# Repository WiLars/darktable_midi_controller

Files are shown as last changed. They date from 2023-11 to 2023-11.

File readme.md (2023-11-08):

# Midi controller for darktable

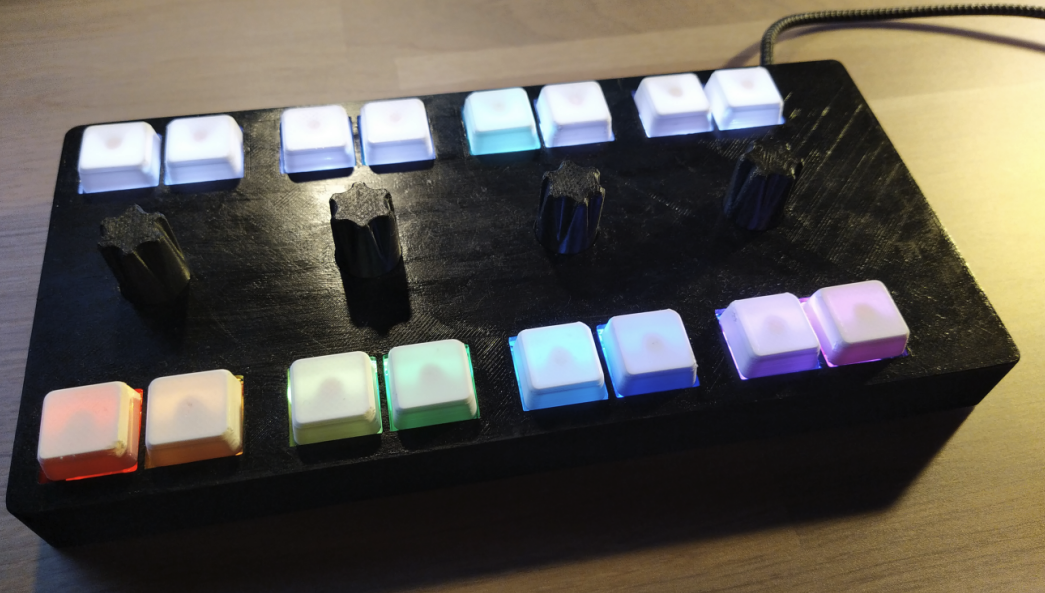
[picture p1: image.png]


- 3D printed housing
  -  stp and stl files available  
- individually illuminated buttons depending on state of the controller using WS2812 RGB LEDs
- arduino compatible pro micro µc
  - extended input channels with 74HC165 shifht registers
  - cherry type mechanical keys
    - 8 top row for mode selction
    - 8 in bottom row for functions
  - 4 alps rotary encoders with button functions
  - powered and connected via usb
- PCB files in KiCad available
- control of darktable via midi protcol
  - fully customizable inside of darktable

## materials
| Part | amount | comment|
| --- | --- | --- |
| PCB | 1 | Kicad files in this repo|
| frontcover | 1 | 3D print|
| backcover | 1 | 3D print|
| LED holder | 1 | 3D print|
| buffer | 7 | 3D print (TPU)|
| encoder knobs | 4 | 3D print|
| keycaps | 16 | 3D print|
| M3x10 screw | 7| |
| micro USB cable| 1 | |
| pro micro atmega32 | 1| arduino compatible cheap MCU|
| 74HC165 | 2|  shift registers|
| cherry type switches | 16 | accordig to taste|
| capacitor 100 nF | 2 | |
| capacitor 1 µF | 2 | or something similar |
| rotary encoder Alps EC12 | 4 | with click|
| pullup resistor | 16 | high resistance recommended > 10k Ohm |
| WS2812 RGB LED | 16 | I used a self adhesive LED strip with 60 LED/m, that way, two can be chained without soldering |
| double tape | some |  to stick the LED holder onto the PCB|
| wire | some | to connect LED strips |

## assembly
- solder al compenents to PCB
- LEDs: this is a little awkward, spacing of LEDs and switches didn't fit and I could't source any reasonably priced THT RGB LEDs
  - two LEDs from the strip are glued to the holder, position is indicated by notches
  - individual strips need to be connected with wire (3 contacts each)
  - LED holder can be glued onto the PCB with some double tape
  - then both strips (top and bottom can be connected to the PCB

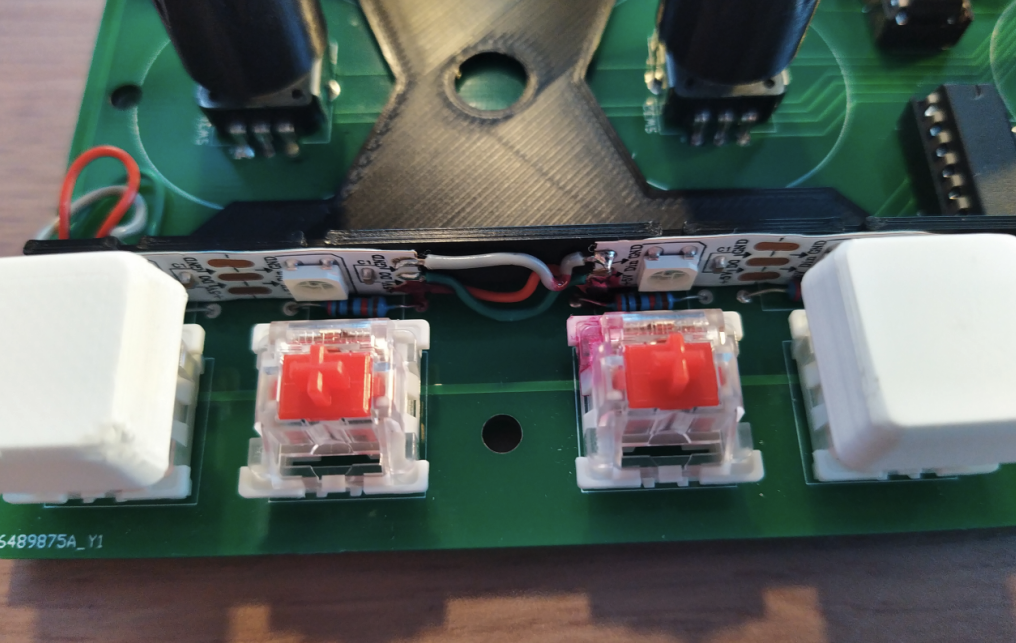
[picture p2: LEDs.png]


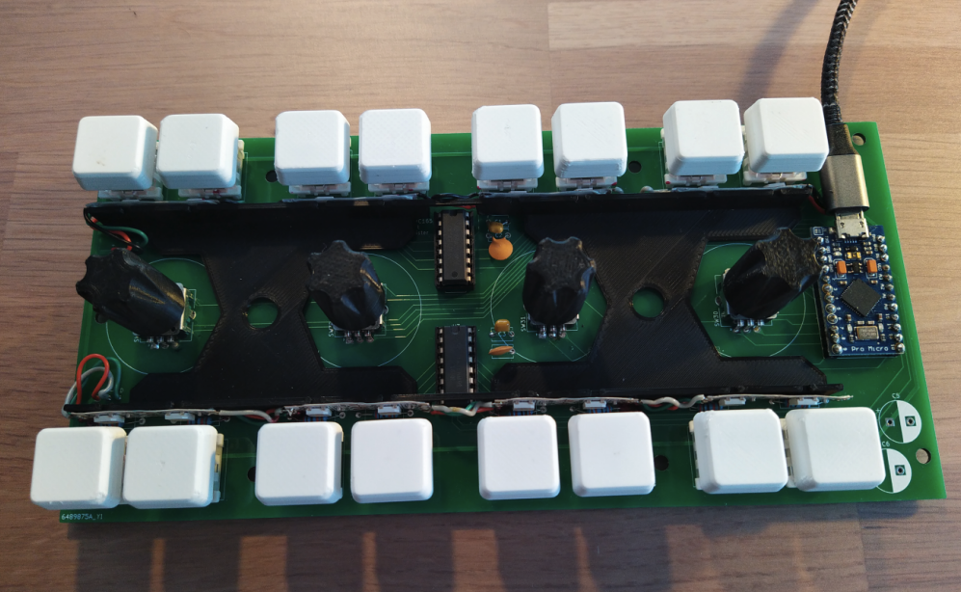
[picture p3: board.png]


- add USB cable
- add TPU buffers to the backcover
- add the case and screws
- knobs and keycaps
- flash arduino SW

## usage
*The controller must be connected during start of darktable, it can only be detected during start!*
after every start, darktable needs to notice that midi CCs are working in relative mode (default is absolute). This can be done by rotating one of the encoders left.

If darktable is running in absolute encoding, input can be reset with ctrl+alt*shift+I then again try to rotate an encoder left.

keymappsings can be imported into darktable: settings -> shortcuts -> import
 => use file *darktable_shortcut_mapping_export*

 With current arduino SW the top row of switches selects the modes, bottom row of buttons and rotary encoders can be assigned to darktable functions

 ## issues
 - darktable does not distinguish for very low "notes" for midi, therefore some buttons cannot be assigned
 - keymapping is not very complete

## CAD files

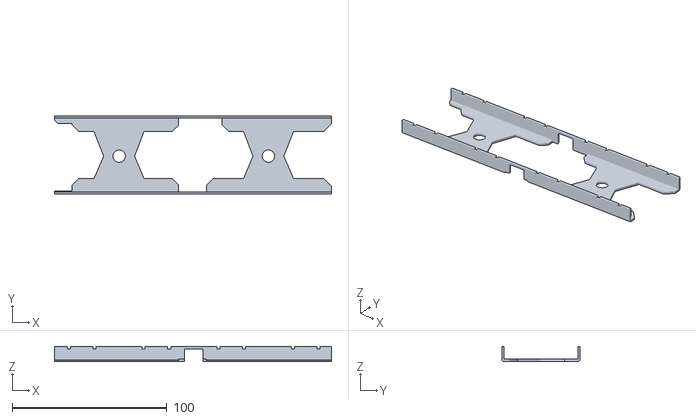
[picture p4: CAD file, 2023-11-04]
3d print parts/LED_holder.stl
179.1 x 50.7 x 9.50

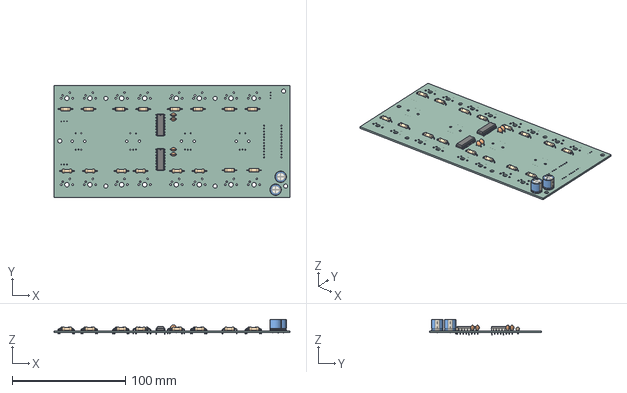
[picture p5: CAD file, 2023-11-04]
PCB_KiCAD/photo console.step
208.3 x 99.1 x 13.3 mm
photo console PCB

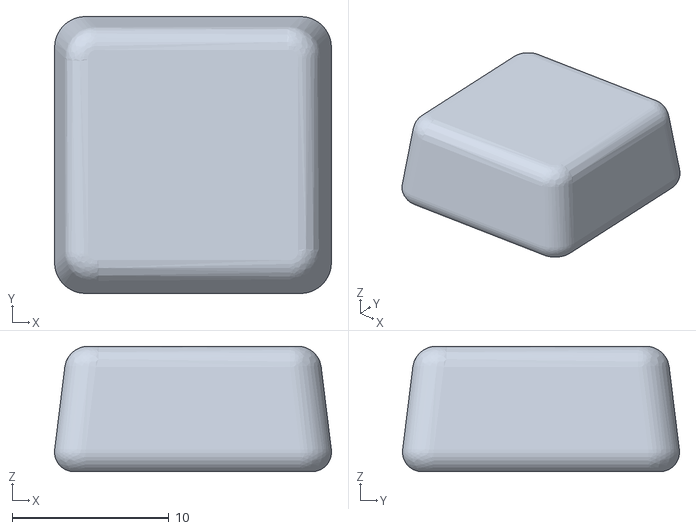
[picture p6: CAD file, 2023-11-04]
3d print parts/key_cap.stl
17.7 x 17.7 x 8.00

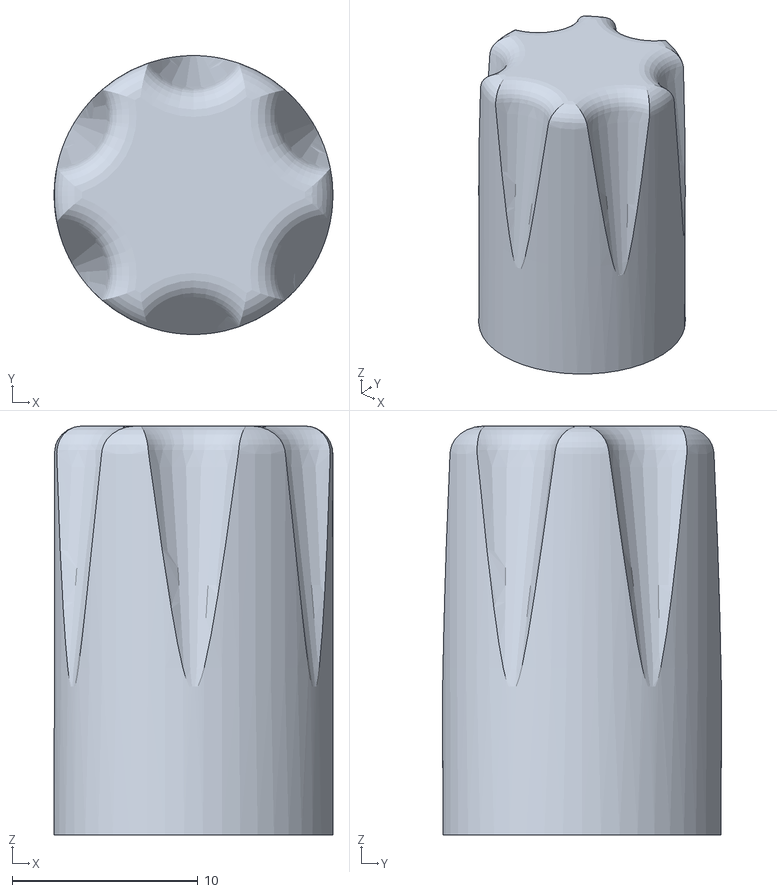
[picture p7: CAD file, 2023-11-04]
3d print parts/rotary_knob.stl
15.0 x 15.0 x 22.0

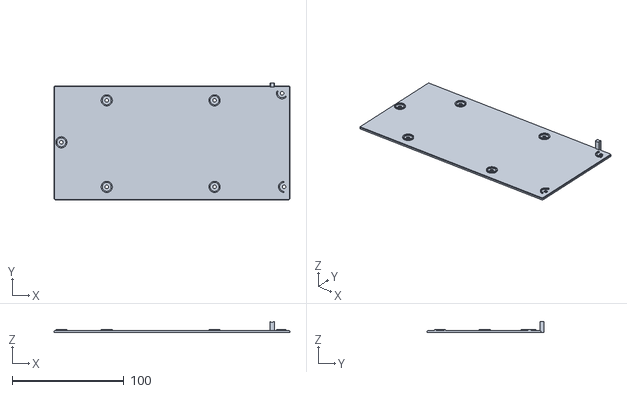
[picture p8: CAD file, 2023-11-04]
3d print parts/backcover.stl
211.3 x 104.6 x 10.2

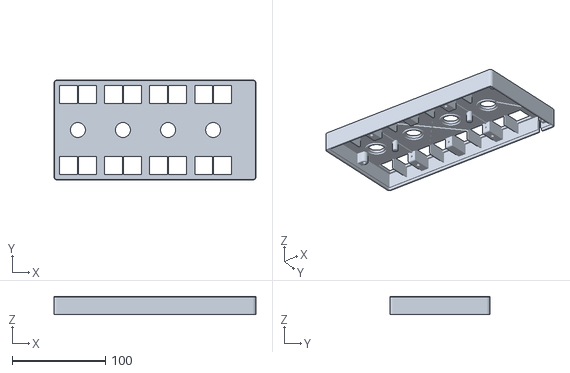
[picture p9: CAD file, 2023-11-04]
3d print parts/housing.stl
216.3 x 107.1 x 19.6

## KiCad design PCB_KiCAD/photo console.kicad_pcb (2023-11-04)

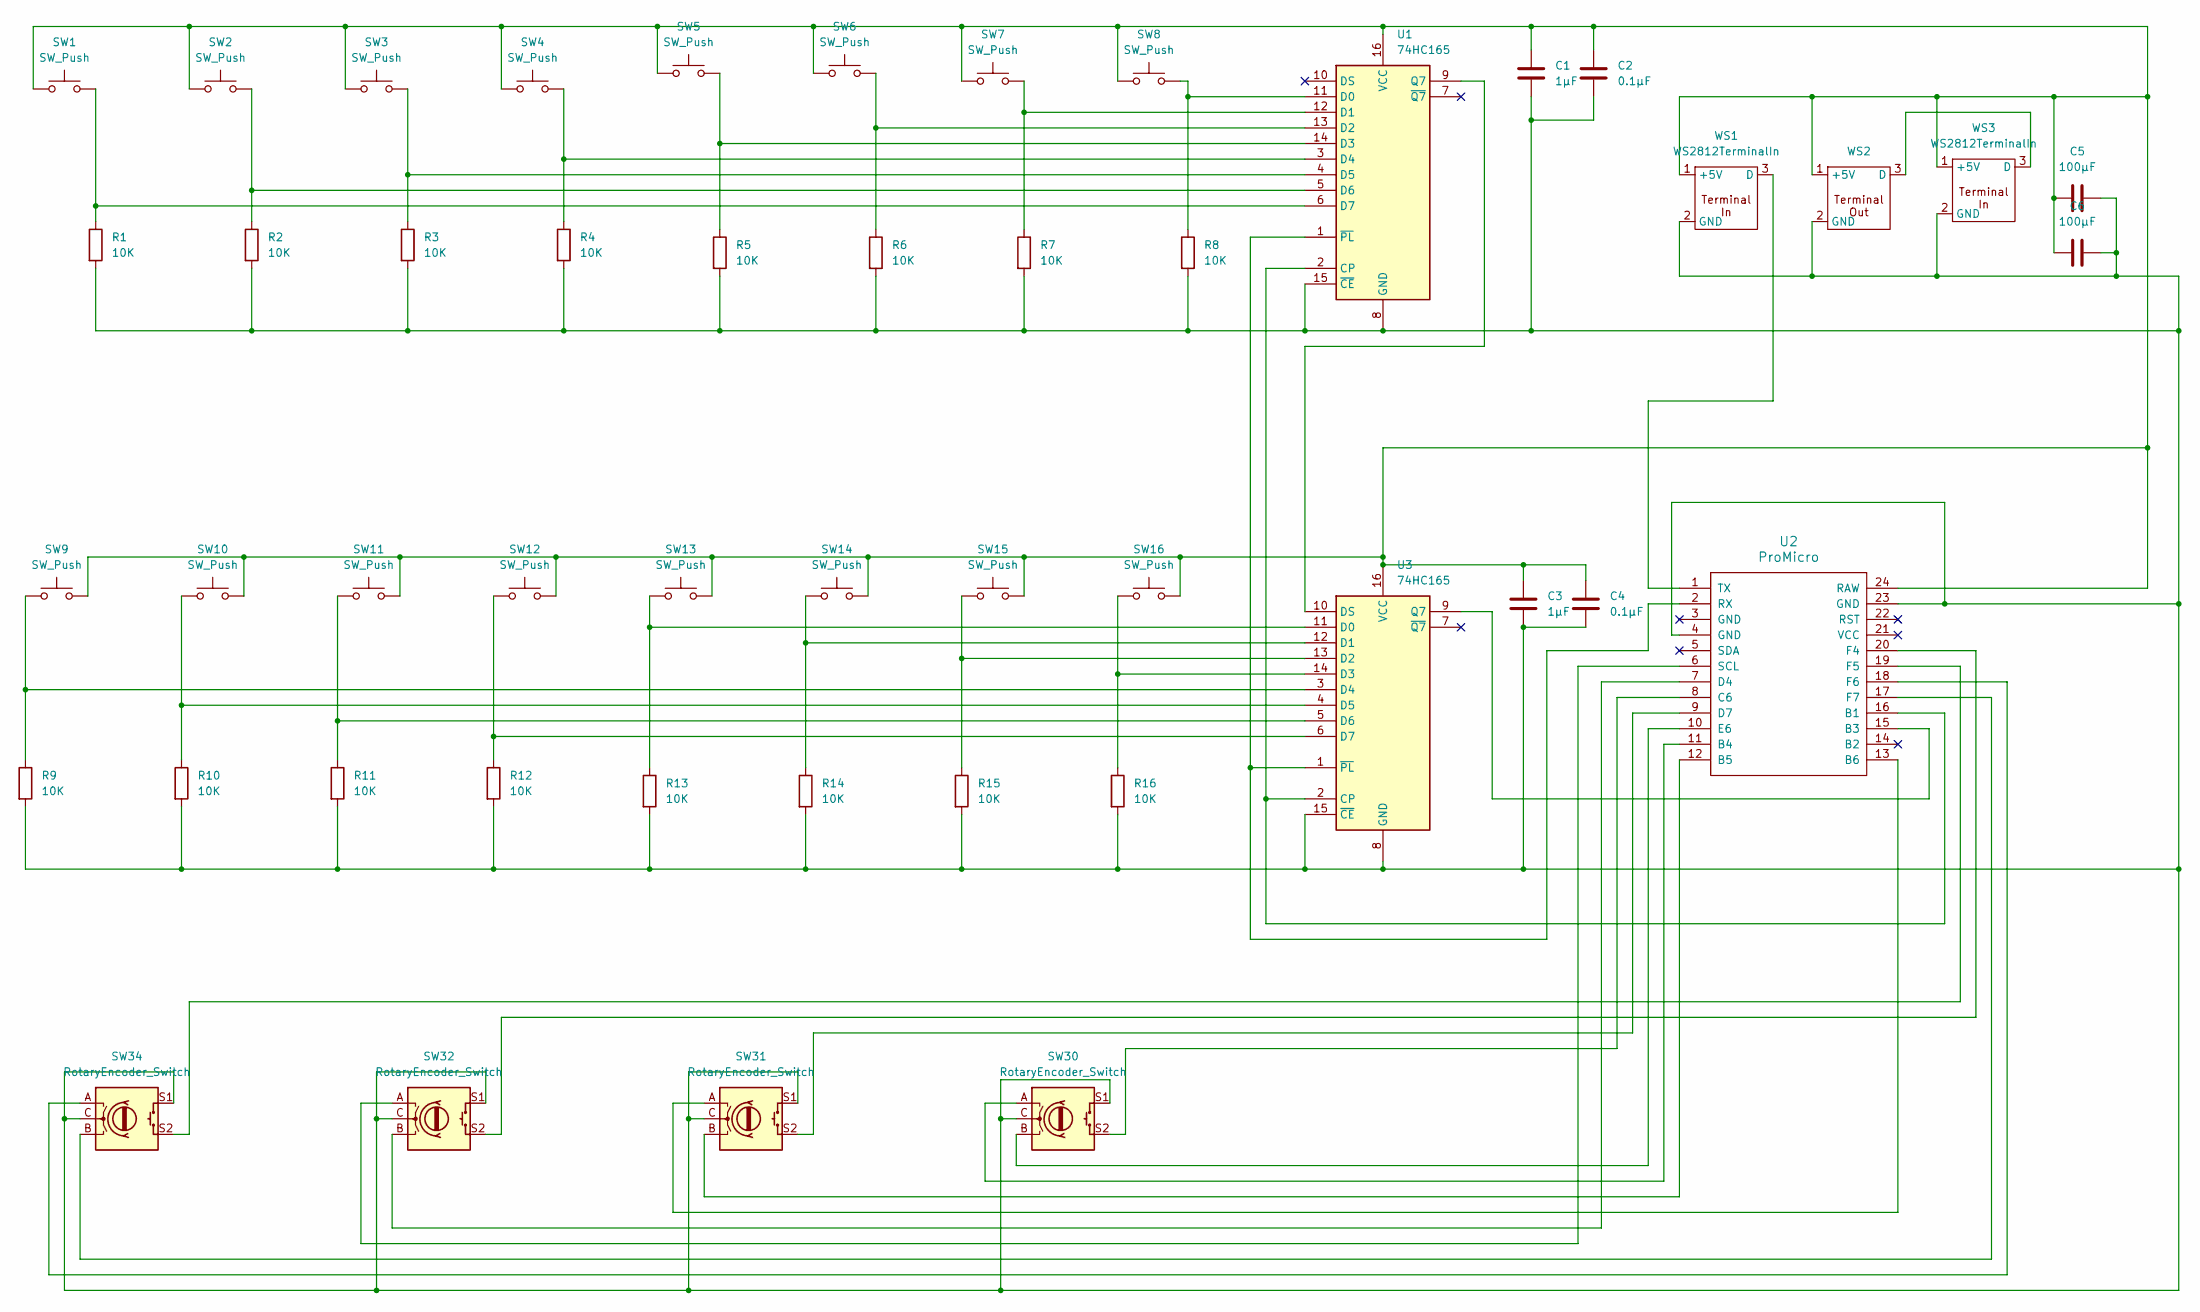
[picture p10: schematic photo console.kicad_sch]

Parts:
C1, C3: 1µF; C_Disc_D5.1mm_W3.2mm_P5.00mm
C2, C4: 0.1µF; C_Disc_D5.1mm_W3.2mm_P5.00mm
C5, C6: 100µF; CP_Radial_D10.0mm_P5.00mm
R1, R2, R3, R4, R5, R6, R7, R8, R9, R10, R11, R12, R13, R14, R15, R16: 10K; R_Axial_DIN0309_L9.0mm_D3.2mm_P12.70mm_Horizontal
SW1, SW2, SW3, SW4, SW5, SW6, SW7, SW8, SW9, SW10, SW11, SW12, SW13, SW14, SW15, SW16: SW_Push; SW_Cherry_MX_1.00u_PCB_center_hole
SW30, SW31, SW32, SW34: RotaryEncoder_Switch; RotaryEncoder_Alps_EC12E-Switch_Vertical_H20mm_CircularMoun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
U1, U3: 74HC165; DIP-16_W7.62mm
U2: ProMicro
WS1, WS3: WS2812TerminalIn; 3 Pin THT
WS2: 3 Pin THT

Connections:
unnamed: U1.2 (CP), U2.16 (B1), U3.2 (CP)
unnamed: R8.1, SW8.2, U1.11 (D0)
unnamed: R7.1, SW7.2, U1.12 (D1)
unnamed: R6.1, SW6.2, U1.13 (D2)
unnamed: R5.1, SW5.2, U1.14 (D3)
unnamed: R4.1, SW4.2, U1.3 (D4)
unnamed: R3.1, SW3.2, U1.4 (D5)
unnamed: R2.1, SW2.2, U1.5 (D6)
unnamed: R1.1, SW1.2, U1.6 (D7)
unnamed: C1.2, C2.2, C3.2, C4.2, C5.2, C6.2, R1.2, R2.2, R3.2, R4.2, R5.2, R6.2, R7.2, R8.2, R9.2, R10.2, R11.2, R12.2, R13.2, R14.2, R15.2, R16.2, SW30.C, SW30.S1, SW31.C, SW31.S1, SW32.C, SW32.S1, SW34.C, SW34.S1, U1.8 (GND), U1.15 (~CE), U2.4 (GND), U2.23 (GND), U3.8 (GND), U3.15 (~CE), WS1.2 (GND), WS2.2 (GND), WS3.2 (GND)
unnamed: U1.9 (Q7), U3.10 (DS)
unnamed: C1.1, C2.1, C3.1, C4.1, C5.1, C6.1, SW1.1, SW2.1, SW3.1, SW4.1, SW5.1, SW6.1, SW7.1, SW8.1, SW9.2, SW10.2, SW11.2, SW12.2, SW13.2, SW14.2, SW15.2, SW16.2, U1.16 (VCC), U2.24 (RAW), U3.16 (VCC), WS1.1 (+5V), WS2.1 (+5V), WS3.1 (+5V)
unnamed: U1.1 (~PL), U2.2 (RX), U3.1 (~PL)
unnamed: U2.15 (B3), U3.9 (Q7)
unnamed: SW30.A, U2.11 (B4)
unnamed: SW31.B, U2.12 (B5)
unnamed: SW31.A, U2.13 (B6)
unnamed: SW30.S2, U2.8 (C6)
unnamed: SW32.B, U2.7 (D4)
unnamed: SW31.S2, U2.9 (D7)
unnamed: SW30.B, U2.10 (E6)
unnamed: SW32.S2, U2.20 (F4)
unnamed: SW34.S2, U2.19 (F5)
unnamed: SW34.A, U2.18 (F6)
unnamed: SW34.B, U2.17 (F7)
unnamed: SW32.A, U2.6 (SCL)
unnamed: U2.1 (TX), WS1.3 (D)
unnamed: R13.1, SW13.1, U3.11 (D0)
unnamed: R14.1, SW14.1, U3.12 (D1)
unnamed: R15.1, SW15.1, U3.13 (D2)
unnamed: R16.1, SW16.1, U3.14 (D3)
unnamed: R9.1, SW9.1, U3.3 (D4)
unnamed: R10.1, SW10.1, U3.4 (D5)
unnamed: R11.1, SW11.1, U3.5 (D6)
unnamed: R12.1, SW12.1, U3.6 (D7)
unnamed: WS2.3 (D), WS3.3 (D)

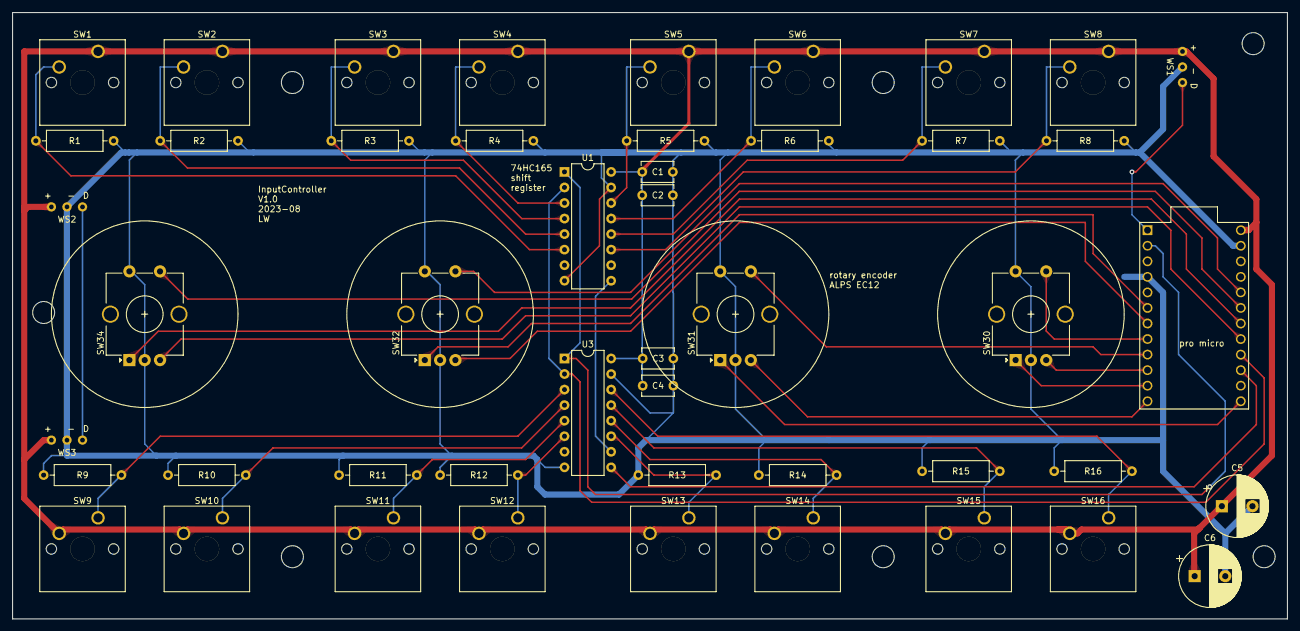
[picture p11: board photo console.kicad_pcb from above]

Board: 2 copper layers, 208.3 x 99.1 mm, 48 parts (0 on the bottom side), 36 nets.

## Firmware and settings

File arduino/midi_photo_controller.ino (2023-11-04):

#include <MIDIUSB.h>
#include <MIDIUSB_Defs.h>
//#include <pitchToNote.h>
//#include <frequencyToNote.h>
//#include <pitchToFrequency.h>


#include <Adafruit_NeoPixel.h>
#include <SPI.h>
#include <ClickEncoder.h>
#include <TimerOne.h>
//#include <Keyboard.h>



const byte LATCH = 0; // shift register pulse

//LED
const byte LEDPIN = 1;

byte LED_R[16] = {127,127,127,127,127,127,127,127,127,127,127,127,127,127,127,127};
byte LED_G[16] = {127,0,127,0,0,0,0,0,0,0,0,0,0,0,0,0};
byte LED_B[16] = {127,127,0,0,0,0,0,127,0,0,0,0,0,0,0,0};
Adafruit_NeoPixel strip = Adafruit_NeoPixel(16, LEDPIN, NEO_GRB + NEO_KHZ800);

byte mode = 0;
byte midi_val = 127;
//-----THIS BLOCK HANDLES ENCODER INPUT-----
//Encoder 1
ClickEncoder *encoder0;      // Dreh-Enkoder mit Klickbutton
ClickEncoder *encoder1;
ClickEncoder *encoder2;      // Dreh-Enkoder mit Klickbutton
ClickEncoder *encoder3;

bool enchold[4];
static int16_t enclastval[4] = {0,0,0,0};

void timerIsr() {
  encoder0->service();
  encoder1->service();
  encoder2->service();
  encoder3->service();
}

void ReadEncoder(int encindex){
  ClickEncoder *encoder;
  if (encindex==0){
    encoder=encoder0;}
  else if (encindex==1){
    encoder=encoder1;}
     else if (encindex==2){
    encoder=encoder2;}
      else if (encindex==3){
    encoder=encoder3;}


int encValue = encoder->getValue();
if (encValue != 0) {
    enclastval[encindex] += encValue;
    byte midi_send =0;
    byte control_channel = mode*4+encindex;
    if (encValue < 0){
      midi_send = 1;}
    else if (encValue > 0){
      midi_send = 127;}
    Serial.print (control_channel);
    Serial.println (midi_send);
 for (uint16_t i=0; i<abs(encValue);i++){ // darktable scheint im relativen encoding nur +1 (=1) und -1 (=127) zu verstehen, deshalb muss für encoder accel das commando einfach mehrfach geschickt werden
    controlChange(0, control_channel, midi_send);
  }
    MidiUSB.flush();
    //Serial.print (encindex);
    //Serial.print (enclastval[encindex] );
    //Serial.println (encValue);
    }

ClickEncoder::Button b = encoder->getButton();     // den Button-Status abfragen
if (b != ClickEncoder::Open) {
    switch (b) {                                     // und entsprechend darauf reagieren
      case ClickEncoder::Clicked:                    // Button wurde einmal angeklickt
        Serial.println (encindex*2+8+mode*16);

        noteOn(0, encindex*2+8+mode*16, 127);
        MidiUSB.flush();
        noteOff(0, encindex*2+8+mode*16, 127);
        MidiUSB.flush();
        break;
      case ClickEncoder::DoubleClicked:              // Doppelklick auf den Button
        Serial.println (encindex*2+8+1+mode*16);
        noteOn(0, encindex*2+8+1+mode*16, 127);
        MidiUSB.flush();
        noteOff(0, encindex*2+8+1+mode*16, 127);
        MidiUSB.flush();
        break;
//      case ClickEncoder::Held:                       // Button gedrueckt halten
//        Serial.print (encindex);
//        Serial.println ("help");
//        break;
//      case ClickEncoder::Released:                   // Button losgelassen (nach gedrueckt halten)
//        Serial.print (encindex);
//        Serial.println ("released");
//        break;
  }
}}

//-------THIS BLOCK HNADLES BUTTON INPUT
void EvalButtons(byte top_bank, byte bottom_bank, byte bottom_bank_old){ 
  for(int i = 0; i < 8; i++, top_bank = top_bank >> 1){
        if (top_bank & 1) {// bit is on
          mode = 7-i; // top_bank is reversed
          Serial.println (mode);
  }}
  for(int i = 0; i < 8; i++, bottom_bank = bottom_bank >> 1, bottom_bank_old = bottom_bank_old >> 1){
    
    int j =0;
        if (bottom_bank & 1) {// bit is on
          if ((bottom_bank^bottom_bank_old) &1){ //only send signal if bit is newly switched off
            if(i > 3){ //reorder channels for bottom line
              j=i-4;}
            else{
              j=i+4;}
            Serial.println (j+mode*16);
            noteOn(0, j+mode*16, 127);
            MidiUSB.flush();
          }}
        else{// bit is off
          
          if ((bottom_bank^bottom_bank_old) &1){ //only send signal if bit is newly switched off
           if(i > 3){ //reorder channels for bottom line
            j=i-4;}
           else{
            j=i+4;}
          noteOff(0, j+mode*16, 127);
          MidiUSB.flush();
          }}
  }
}

// --- LEDS -----
void setLEDs(){
  byte basecol[3] = {255,255,220}; //RGB
  byte color_active[3] = {64,255,64};
  byte *color; //RGB
  byte color_red[3] = {255,0,0}; //RGB
  byte color_orange[3] = {255,160,0}; //RGB
  byte color_yellow[3] = {192,255,0}; //RGB
  byte color_green[3] = {0,255,0}; //RGB
  byte color_torquise[3] = {0,255,255}; //RGB
  byte color_blue[3] = {0,0,255}; //RGB
  byte color_purple[3] = {255,0,255}; //RGB
  byte color_magenta[3] = {255,0,160}; //RGB
  byte dimming = 192;
  byte dimming_passive = 96; 
  byte dimming_local;
  
  for (uint16_t i=0; i<16;i++){
    color =basecol;
    if (mode == 4){
      switch (i){
        case 8:
        color=color_red;
        break;
        case 9:
        color=color_orange;
        break;
        case 10:
        color=color_yellow;
        break;
        case 11:
        color=color_green;
        break;
        case 12:
        color=color_torquise;
        break;
        case 13:
        color=color_blue;
        break;
        case 14:
        color=color_purple;
        break;
        case 15:
        color=color_magenta;
        break;
        default:
        color =basecol;
        break;
    }}
    if (mode == 7){
      switch (i){
        case 8:
        color=color_red;
        break;
        case 9:
        color=color_orange;
        break;
        case 10:
        color=color_green;
        break;
        case 11:
        color=color_blue;
        break;
        case 12:
        color=color_magenta;
        break;
        case 13:
        color=basecol;
        break;
        case 14:
        color=basecol;
        break;
        case 15:
        color=basecol;
        break;
        default:
        color =basecol;
        break;
    }}
    if (i == 7-mode){
      dimming_local = dimming;
      color  = color_active;
    }
    else{
      dimming_local = dimming_passive;
      }
    
    strip.setPixelColor(i,strip.Color(color[0]&dimming_local, color[1]&dimming_local,color[2]&dimming_local));
    }
  strip.show();
  
}



// ------Arduino MIDI functions MIDIUSB Library
void controlChange(byte channel, byte control, byte value) {
  midiEventPacket_t event = {0x0B, 0xB0 | channel, control, value};
  MidiUSB.sendMIDI(event);
}
void noteOn(byte channel, byte pitch, byte velocity) {
  midiEventPacket_t noteOn = {0x09, 0x90 | channel, pitch, velocity};
  MidiUSB.sendMIDI(noteOn);
}

void noteOff(byte channel, byte pitch, byte velocity) {
  midiEventPacket_t noteOff = {0x08, 0x80 | channel, pitch, velocity};
  MidiUSB.sendMIDI(noteOff);}

//------SETUP FUNCTION
void setup ()
{
strip.begin();
strip.show();

// shift reg
  SPI.begin ();
  Serial.begin (115200);
  Serial.println ("Begin switch test.");
  pinMode (LATCH, OUTPUT);
  digitalWrite (LATCH, HIGH);
// encoders
  encoder0 = new ClickEncoder(19, 18, 20, 4); // den Dreh-Enkoder initialisieren
  encoder1 = new ClickEncoder(3, 4, 21, 4);
  encoder2 = new ClickEncoder(10, 9, 6, 4); // den Dreh-Enkoder initialisieren
  encoder3 = new ClickEncoder(8, 7, 5, 4);
  //encoder0->setAccelerationEnabled(false);
  //encoder1->setAccelerationEnabled(false);
  //Timer
  Timer1.initialize(1000);                      // den Interrupt-Timer fuer den Dreh-Enkoder initialisieren
  Timer1.attachInterrupt(timerIsr);
//LEDs
  setLEDs();     
}  // end of setup


byte switchBank1;
byte switchBank2;
byte oldswitchBank1;
byte oldswitchBank2;


//----- LOOP function

void loop ()
{
  digitalWrite (LATCH, LOW);    // pulse the parallel load latch
  digitalWrite (LATCH, HIGH);
  switchBank1 = SPI.transfer (0);
  switchBank2 = SPI.transfer (0);
  if (switchBank1 != oldswitchBank1 or switchBank2 != oldswitchBank2){
    //Serial.print (switchBank1);
    //Serial.println (switchBank2);
    EvalButtons(switchBank2, switchBank1, oldswitchBank1);
    oldswitchBank1 = switchBank1;
    oldswitchBank2 = switchBank2;
    delay(10);
    setLEDs();
    }
//  delay (10);   // debounce
  
  ReadEncoder(0);
  ReadEncoder(1);
  ReadEncoder(2);
  ReadEncoder(3);

  
}  // end of loop
